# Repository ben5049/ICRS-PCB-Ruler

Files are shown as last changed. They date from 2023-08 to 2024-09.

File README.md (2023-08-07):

# ICRS PCB Ruler

A 15cm PCB ruler designed for Imperial College Robotics Society. It can be easily adapted/rebranded using the KiCad project in this repository.

Front:

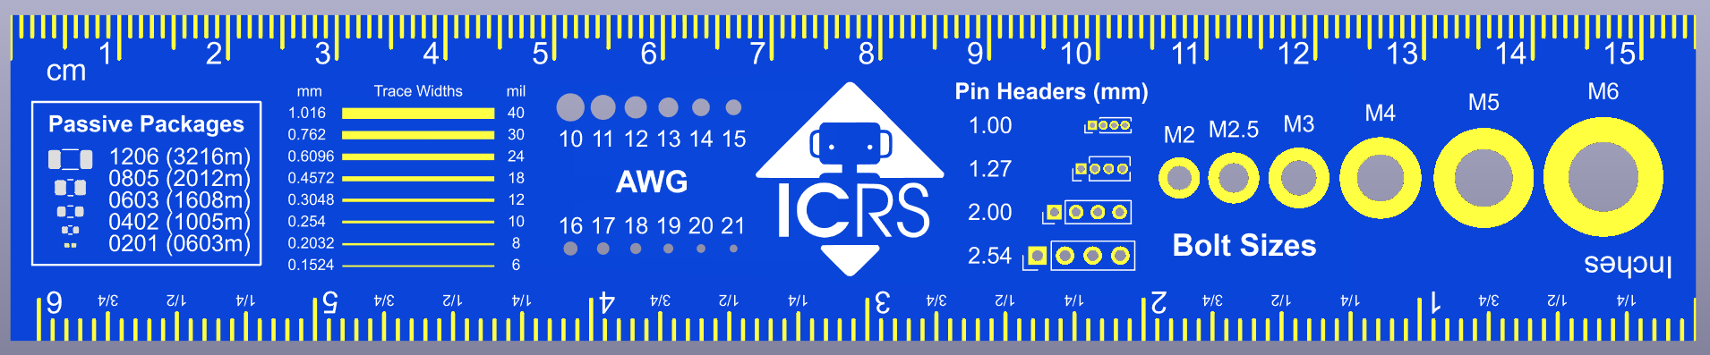
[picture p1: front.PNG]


Back:

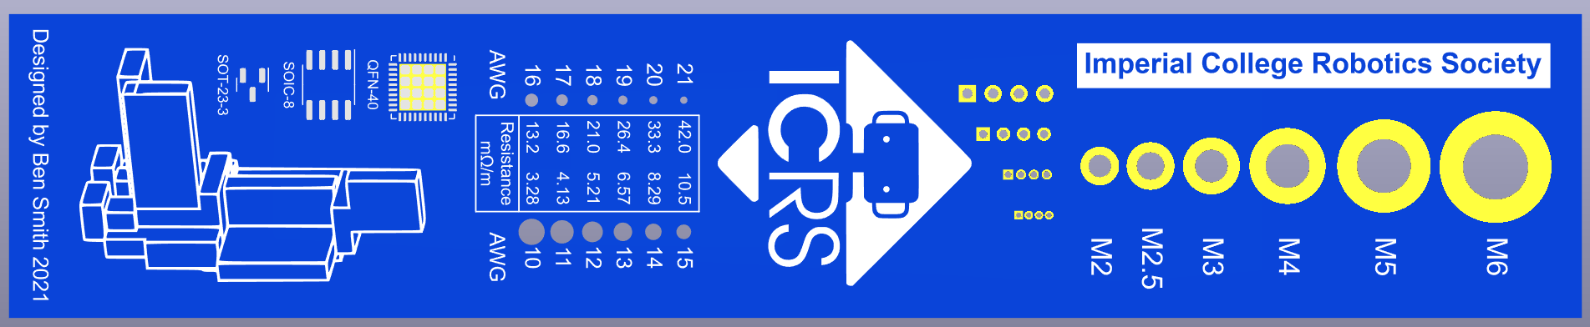
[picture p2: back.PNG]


## KiCad Project
To open this project in KiCad 7.0 clone this repository and open the .kicad_pro file in [Ruler_KiCad](Ruler_KiCad). Next open the PCB editor and go to `Preferences > Manage Footprint Libraries > Add Existing` (the folder icon below the list of libraries). Then navigate to `Ruler_KiCad/ruler_footprints` and click "select folder". This is in order to get the custom footprints used in this project.

## Ordering
The gerber files needed for ordering can be found in [Ruler_gerbers.zip](Ruler_KiCad/Ruler_gerbers/Ruler_gerbers.zip). Simply upload this .zip file to any PCB manufacturer's website.

The recommended specifications for ordering this PCB are as follows:
* 2 Layers
* 1.6mm thick FR4
* Blue soldermask
* White silkscreen
* ENIG surface finish
* <= 1 oz Copper weight
* Tented vias (doesn't matter as there are no vias)
* +- 0.2mm Board outline tolerance
* Remove order number

Using [JLCPCB's](https://jlcpcb.com/) pricing, the cost of ordering x number of boards has been plotted in [Pricing.xlsx](Pricing.xlsx).

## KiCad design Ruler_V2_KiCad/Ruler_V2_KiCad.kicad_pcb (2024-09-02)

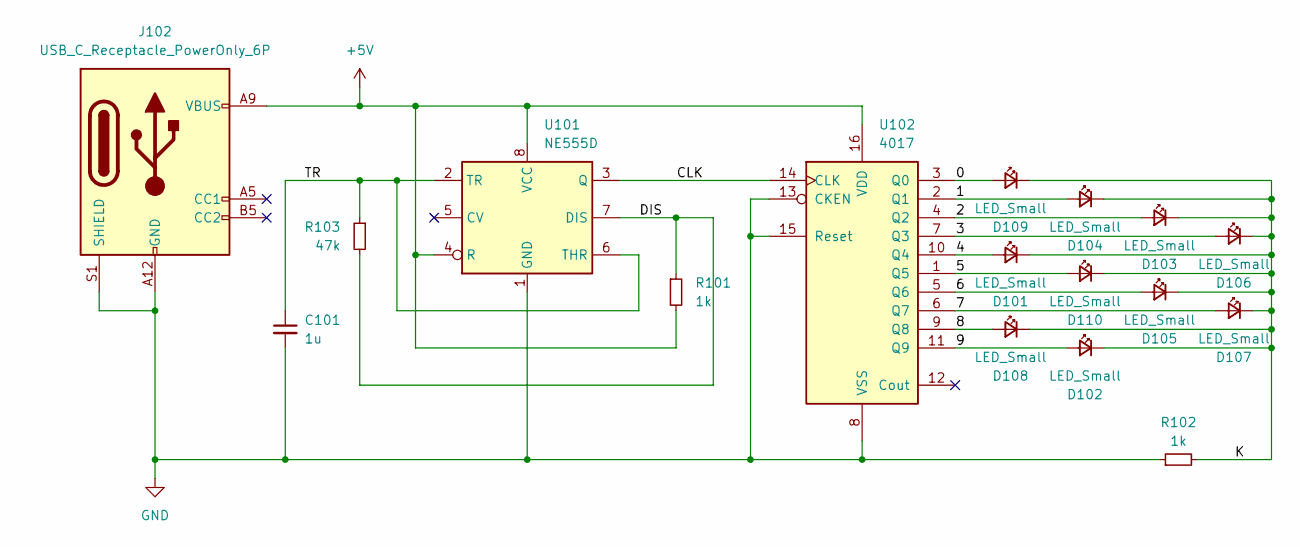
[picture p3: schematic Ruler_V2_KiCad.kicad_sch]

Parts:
C101: 1u; C_0402_1005Metric
D101, D102, D103, D104, D105, D106, D107, D108, D109, D110: LED_Small; LED_0402_1005Metric
J102: USB_C_Receptacle_PowerOnly_6P; USB_C_Receptacle_GCT_USB4135-GF-A_6P_TopMnt_Horizontal
R101, R102: 1k; R_0402_1005Metric
R103: 47k; R_0402_1005Metric
U101: NE555D; SOIC-8_3.9x4.9mm_P1.27mm
U102: 4017; SOP-16_3.9x9.9mm_P1.27mm

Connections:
+5V: J102.A9 (VBUS), J102.B9 (VBUS), R101.2, U101.4 (R), U101.8 (VCC), U102.16 (VDD)
/0: D109.2 (A), U102.3 (Q0)
/1: D104.2 (A), U102.2 (Q1)
/2: D103.2 (A), U102.4 (Q2)
/3: D106.2 (A), U102.7 (Q3)
/4: D101.2 (A), U102.10 (Q4)
/5: D110.2 (A), U102.1 (Q5)
/6: D105.2 (A), U102.5 (Q6)
/7: D107.2 (A), U102.6 (Q7)
/8: D108.2 (A), U102.9 (Q8)
/9: D102.2 (A), U102.11 (Q9)
/CLK: U101.3 (Q), U102.14 (CLK)
/DIS: R101.1, R103.2, U101.7 (DIS)
/K: D101.1 (K), D102.1 (K), D103.1 (K), D104.1 (K), D105.1 (K), D106.1 (K), D107.1 (K), D108.1 (K), D109.1 (K), D110.1 (K), R102.2
/TR: C101.1, R103.1, U101.2 (TR), U101.6 (THR)
GND: C101.2, J102.A12 (GND), J102.B12 (GND), J102.S1 (SHIELD), R102.1, U101.1 (GND), U102.8 (VSS), U102.13 (CKEN), U102.15 (Reset)

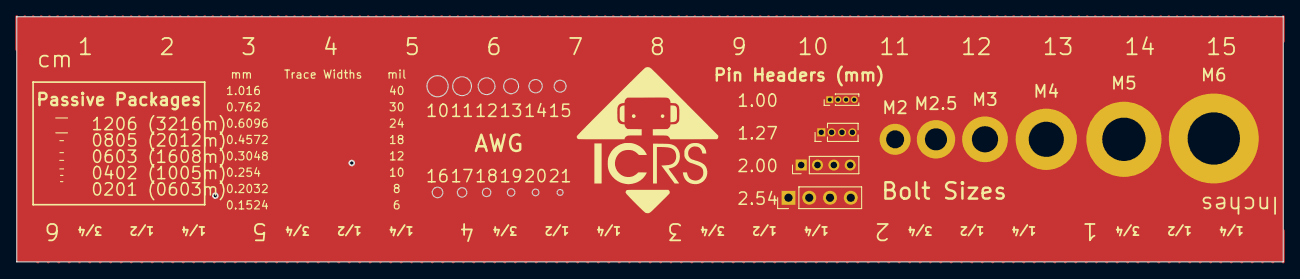
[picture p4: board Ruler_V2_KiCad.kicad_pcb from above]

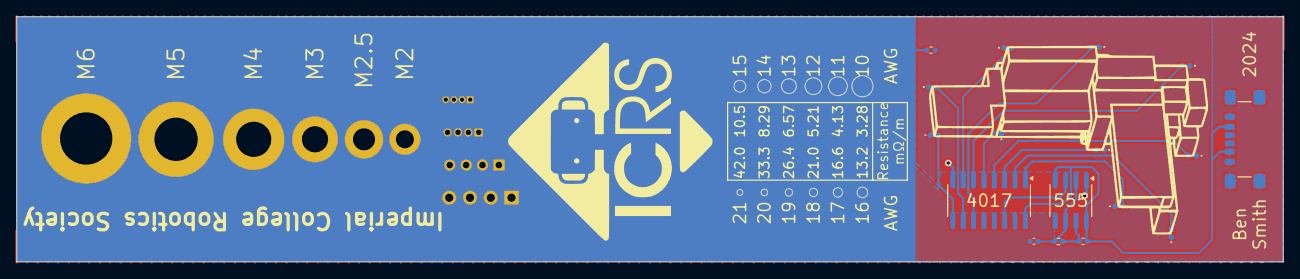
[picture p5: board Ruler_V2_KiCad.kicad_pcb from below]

Board: 2 copper layers, 155.0 x 30.0 mm, 17 parts (17 on the bottom side), 16 nets.
